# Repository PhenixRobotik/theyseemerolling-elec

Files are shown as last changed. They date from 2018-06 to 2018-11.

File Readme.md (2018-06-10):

# Électronique pour "They see me rolling",  la base roulante de PhenixRobotik.

<div class="alert alert-warning">
    This project requires KiCAD 5.0 and is not compatible with previous versions (software and libraries).
</div>

* Stm32f3 (?)
  * Voltage instrumentation (power, digital)
  * Power current instrumentation

* IOs :
  * Power alimentation
  * Digital alimentation
  * JTAG debug (daisy-chain)
  * CAN Bus (daisy-chain)
  * UART ?

* 2 roues codeuses + 2 encodeurs rotatifs :
  * (suggestion salamandar) [Broadcom AS22-M570-xxxx](https://www.mouser.fr/ProductDetail/Broadcom/AS22-M570-4U14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)
    * Ø22mm × 10.9mm
    * 360 cpr to 2048 cpr
    * dual-channel + index channel
    * 5V

* 2 moteurs Maxon DC + 2 encodeurs rotatifs

* Driver moteurs
  * (suggestion salamandar) [ST L6207](http://www.st.com/content/st_com/en/products/motor-drivers/brushed-dc-motor-drivers/l6207.html)
    * POWERSO36
    * Operating supply voltage from 8 to 52 V
    * 5.6 A output peak current (2.8 A DC)
    * PWM current controllers
    * Operating frequency up to 100 KHz
    
* Current measurement
    * torque estimation / control
    * Way of doing it : Use a driver which provides this feature / shunt resistor / Hall effect sensor ?
    
* Architecture:
    * One single PCB card
    * One motor driver card (speed + torque control) + one position (+ odometrie ?) card ( = carte kiwi ?)
    * Two motor driver cards (speed + torque control) + one position (+ odometrie ?) card ( = carte kiwi ?)

## Eventually :

* IMU / 9-axes
* ...

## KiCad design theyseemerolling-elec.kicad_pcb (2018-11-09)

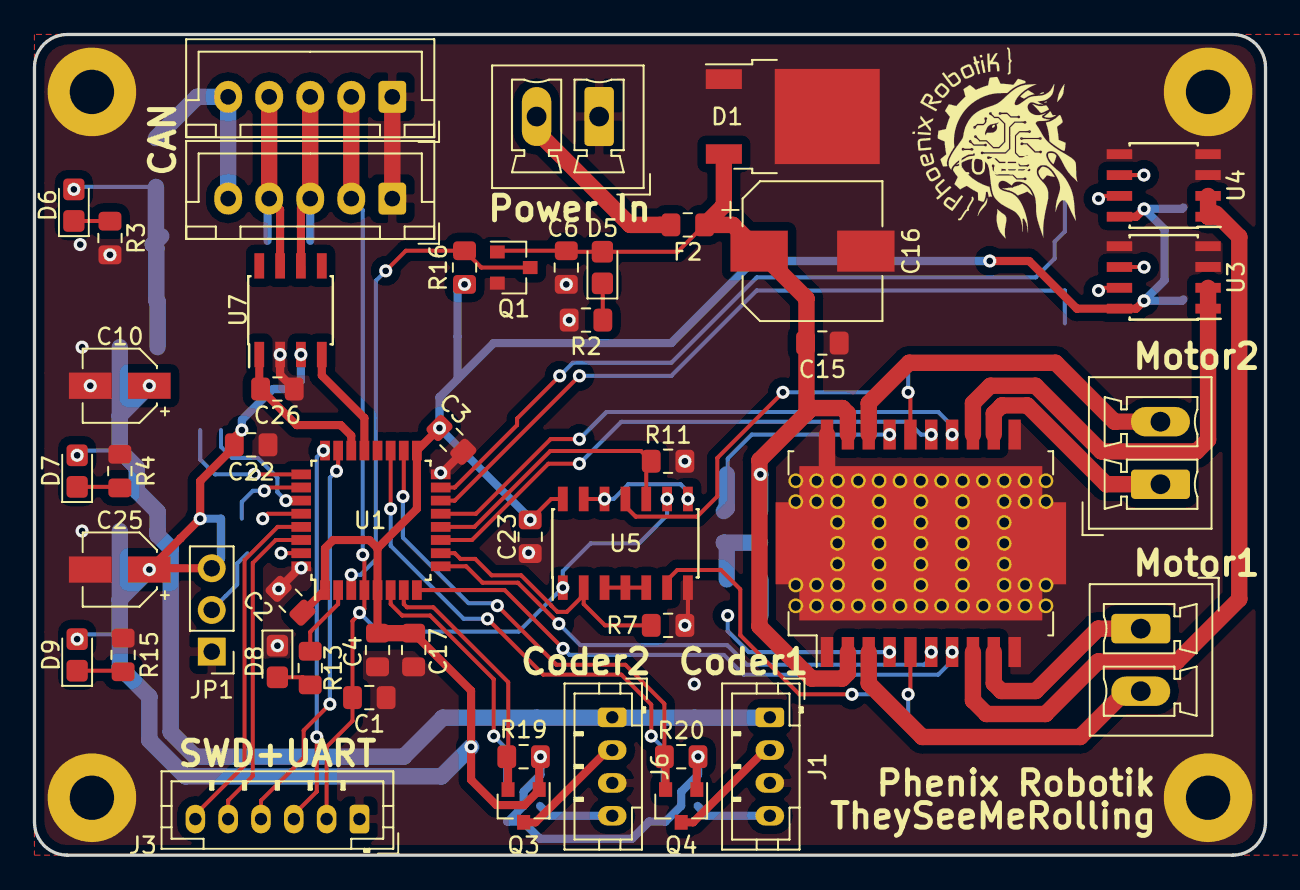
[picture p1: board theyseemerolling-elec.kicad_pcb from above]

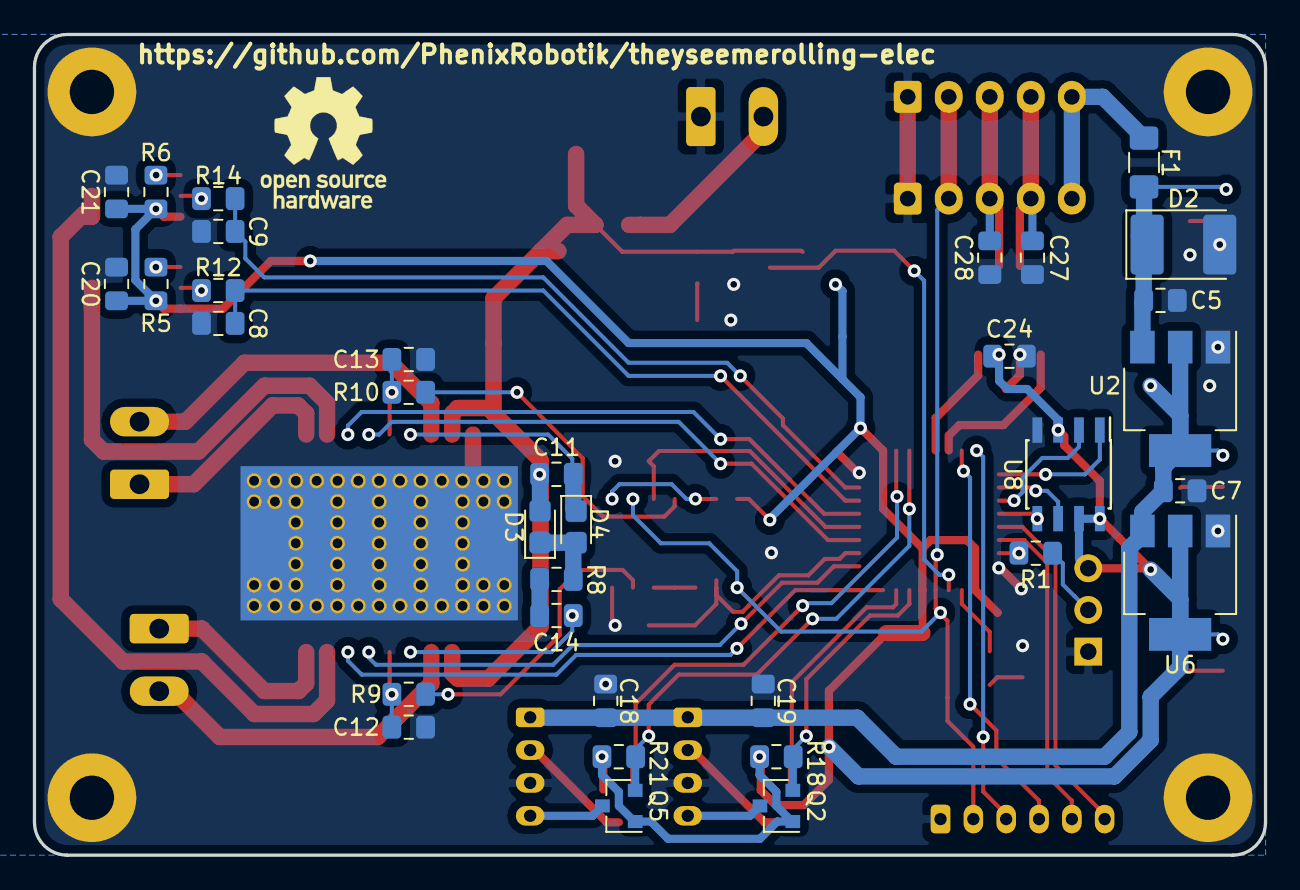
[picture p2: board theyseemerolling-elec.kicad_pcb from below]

Board: 2 copper layers, 75.0 x 50.0 mm, 88 parts (35 on the bottom side), 65 nets.

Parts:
C1, C2, C3, C4, C5, C7, C15: 100n; C_0805_2012Metric_Pad1.15x1.40mm_HandSolder
C6: C; C_0805_2012Metric_Pad1.15x1.40mm_HandSolder
C8, C9: 1n; C_0805_2012Metric_Pad1.15x1.40mm_HandSolder
C10, C25: 10u; CP_Elec_4x5.4
C11: 220n; C_0805_2012Metric_Pad1.15x1.40mm_HandSolder
C12, C13: 5.6n; C_0805_2012Metric_Pad1.15x1.40mm_HandSolder
C14: 10n; C_0805_2012Metric_Pad1.15x1.40mm_HandSolder
C16: 100u; CP_Elec_8x10
C17: 4.7u; C_0805_2012Metric_Pad1.15x1.40mm_HandSolder
C18, C19, C20, C21, C22, C23, C24: 100nF; C_0805_2012Metric_Pad1.15x1.40mm_HandSolder
C26, C27, C28: 100p; C_0805_2012Metric_Pad1.15x1.40mm_HandSolder
D1: D_Schottky_AAK; TO-252-2
D2: D; D_2114_3652Metric_Castellated
D3, D4: 1N4148; D_0805_2012Metric_Castellated
D5, D6, D7, D8, D9: LED_ALT; LED_0805_2012Metric_Castellated
F1: Polyfuse 2A; Fuse_1206_3216Metric_Pad1.42x1.75mm_HandSolder
F2: 5A; Fuse_0805_2012Metric_Pad1.15x1.40mm_HandSolder
IC2: L6205PD; ST_PowerSO-20_SlugDown_ThermalVias
J1: Conn_Encoder1; JST_PH_B4B-PH-K_1x04_P2.00mm_Vertical
J2: Conn_Power_In; PhoenixContact_MCV_1,5_2-G-3.81_1x02_P3.81mm_Vertical
J3: Conn_SWD_UART; JST_PH_B6B-PH-K_1x06_P2.00mm_Vertical
J4: Conn_Mot1; PhoenixContact_MCV_1,5_2-G-3.81_1x02_P3.81mm_Vertical
J5: Conn_Mot2; PhoenixContact_MCV_1,5_2-G-3.81_1x02_P3.81mm_Vertical
J6: Conn_Encoder2; JST_PH_B4B-PH-K_1x04_P2.00mm_Vertical
J7, J8: CAN_conn; JST_XH_B05B-XH-A_1x05_P2.50mm_Vertical
JP1: JP_Select_Boot; PinHeader_1x03_P2.54mm_Vertical
LOGO1: Logo_Open_Hardware_Large; OSHW-Logo_7.5x8mm_SilkScreen
LOGO2: Logo_Open_Hardware_Small; Logo_14,5mm
MK1, MK2, MK3, MK4: MountingHole_Pad; MountingHole_2.7mm_M2.5_Pad
Q1, Q2, Q3, Q4, Q5: BSS138; SOT-23
R1, R5, R6, R7, R11, R16: 10kR; R_0805_2012Metric_Pad1.15x1.40mm_HandSolder
R2, R3, R4, R15: R_LED; R_0805_2012Metric_Pad1.15x1.40mm_HandSolder
R8: 100R; R_0805_2012Metric_Pad1.15x1.40mm_HandSolder
R9, R10: 100k; R_0805_2012Metric_Pad1.15x1.40mm_HandSolder
R12, R14: R_Sense; R_0805_2012Metric_Pad1.15x1.40mm_HandSolder
R13: 1kR; R_0805_2012Metric_Pad1.15x1.40mm_HandSolder
R18, R19, R20, R21: R; R_0805_2012Metric_Pad1.15x1.40mm_HandSolder
U1: STM32F303K8Tx; LQFP-32_7x7mm_P0.8mm
U2: LD1117S50TR_SOT223; SOT-223-3_TabPin2
U3, U4: ACS711xLCTR-12AB; SOIC-8_3.9x4.9mm_P1.27mm
U5: 74HC00; SOIC-14_3.9x8.7mm_P1.27mm
U6: LD1117S33TR_SOT223; SOT-223-3_TabPin2
U7: TCAN332; SOIC-8_3.9x4.9mm_P1.27mm
U8: AT25SF041; SOIC-8_3.9x4.9mm_P1.27mm

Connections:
+3V3: C2.1, C3.1, C4.1, C17.2, C20.2, C21.2, C22.2, C23.1, C24.1, C25.1, D9.2, JP1.3, Q2.1, Q3.1, Q4.1, Q5.1, R5.1, R6.1, R16.1, R18.1, R19.2, R20.1, R21.2, U1.1, U1.5, U1.17, U3.8, U4.8, U5.14, U6.2, U7.3, U8.3, U8.7, U8.8
+5V: C7.1, C10.1, C18.1, C19.1, D7.2, J1.1, J6.1, U2.2, U6.3
/CAN/+7V_CAN: F1.2, J7.5, J8.5
/CAN/NRST: C1.2, J3.2, J7.2, J8.2, U1.4, U5.1, U5.9
/DualDCDriver/EN_A: R9.2, U5.6
/DualDCDriver/EN_B: R10.2, U5.11
/DualDCDriver/IN1_A: IC2.6, U1.9
/DualDCDriver/IN1_B: IC2.14, U1.13
/DualDCDriver/IN2_A: IC2.7, U1.8
/DualDCDriver/IN2_B: IC2.15, U1.11
/DualDCDriver/M1+: IC2.9, J4.1
/DualDCDriver/M1-: IC2.3, J4.2
/DualDCDriver/M2+: IC2.12, J5.1
/DualDCDriver/M2-: IC2.18, J5.2
/DualDCDriver/Sense_A: R14.1, U4.7
/DualDCDriver/Sense_A_Fault: R6.2, U4.6
/DualDCDriver/Sense_B: R12.1, U3.7
/DualDCDriver/Sense_B_Fault: R5.2, U3.6
/f3/ABOUT_DA_POWER: Q1.3, R16.2, U1.3
/f3/CAN_RX: U1.21, U7.4
/f3/CAN_TX: C26.1, U1.22, U7.1
/f3/EN_A_and_NRST: R7.2, U1.10, U5.2
/f3/EN_B_and_NRST: R11.1, U1.12, U5.10
/f3/Encoder_1_A: J1.2, Q4.3
/f3/Encoder_1_B: J1.4, Q5.3
/f3/Encoder_2_A: J6.2, Q3.3
/f3/Encoder_2_B: J6.4, Q2.3
/f3/MISO: U1.27, U8.2
/f3/MOSI: U1.28, U8.5
/f3/RX_1: J3.5, U1.30
/f3/SCK: U1.26, U8.6
/f3/Sense_A_Filtered: C9.1, R14.2, U1.15
/f3/Sense_B_Filtered: C8.1, R12.2, U1.14
/f3/TCK: J3.3, U1.24
/f3/TMS: J3.4, U1.23
/f3/TX_1: J3.6, U1.29
GND: C1.1, C2.2, C3.2, C4.2, C5.2, C6.2, C7.2, C8.2, C9.2, C10.2, C12.2, C13.2, C15.2, C16.2, C17.1, C18.2, C19.2, C20.1, C21.1, C22.1, C23.2, C24.2, C25.2, C26.2, C27.1, C28.2, D1.1, D1.2, D2.2, D8.1, IC2.1, IC2.10, IC2.11, IC2.20, IC2.21, J1.3, J2.1, J3.1, J6.3, J7.1, J8.1, JP1.1, MK1.1, MK2.1, MK3.1, MK4.1, Q1.2, R2.2, R3.2, R4.2, R7.1, R11.2, R15.2, U1.16, U1.32, U2.1, U3.3, U3.4, U3.5, U4.3, U4.4, U4.5, U5.7, U6.1, U7.2, U8.4
unnamed: C5.1, D2.1, D6.2, F1.1, U2.3
unnamed: C11.2, D4.1, IC2.17
unnamed: C12.1, IC2.5, R9.1
unnamed: C13.1, IC2.16, R10.1
unnamed: C14.1, IC2.4
unnamed: C14.2, R8.1
unnamed: C27.2, J7.4, J8.4, U7.7
unnamed: C28.1, J7.3, J8.3, U7.6
unnamed: D3.1, D4.2, R8.2
unnamed: D5.1, R2.1
unnamed: D6.1, R3.1
unnamed: D7.1, R4.1
unnamed: D8.2, R13.1
unnamed: D9.1, R15.1
unnamed: F2.2, J2.2
unnamed: IC2.8, U4.1, U4.2
unnamed: IC2.13, U3.1, U3.2
unnamed: JP1.2, R1.2
unnamed: Q2.2, R18.2, U1.6
unnamed: Q3.2, R19.1, U1.7
unnamed: Q4.2, R20.2, U1.18
unnamed: Q5.2, R21.1, U1.19
unnamed: R1.1, U1.31
unnamed: R13.2, U1.2
unnamed: U1.25, U8.1
unnamed: U5.3, U5.4, U5.5
unnamed: U5.8, U5.12, U5.13
VCC: C6.1, C11.1, C15.1, C16.1, D1.3, D3.2, D5.2, F2.1, IC2.2, IC2.19, Q1.1

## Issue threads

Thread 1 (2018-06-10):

[power_regul] Diode D1 reverse

Salamandar, 2018-06-10:
La diode D1 reverse sert, je suppose, à absorber le courant en cas d'alim inversée.
Si c'est le cas, pourquoi ne pas mettre (aussi ?) une diode en directe entre power_input et power ?

LTrMN, 2018-06-10:
C'est ça, et quand il y a inversion le fusible doit sauter (attention au dimensionnement de la diode par rapport au fusible). Si on ne met pas la diode en inverse, c'est pour éviter de faire passer toute la puissance dans cette diode, et donc de chauffer et perdre de l'énergie inutilement.

Salamandar, 2018-06-10:
> Si on ne met pas la diode en inverse

Tu voulais dire directe ?

En tout cas je comprends, donc je retire ce que j'ai dit.

LTrMN, 2018-06-10:
Oui

Closed 2018-06-10.

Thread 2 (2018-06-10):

[power_regul] Elec_input = 7V, regul 5v

Salamandar, 2018-06-10:
Ce qu'il se passe sur le bus n'est pas contrôlé par la board (interférences, proximité des câbles de puissance, etc), il faudrait donc un régul 5v sur la board.

Cela "oblige" à fournir par le bus plus de 5v (parce que le régul sera certainement un step down). Certaines équipes se fixent sur 7.5v. Sur notre aspirateur robot je crois que c'était 7V. Mais dans le détail, on s'en fout : Il faut un régul 5v (en parallèle ou en amont du régul 3v3 ?).

LTrMN, 2018-06-10:
en amont avec de LOD (faible chute pour le 3.3V), on perd moins de puissance, après oui j'hésitais entre propager un +5V qui sert à tout les processeurs et capteurs, avec éventuellement une autre régul à +3.3V, ou propager une tension supérieure à 5V (au moins 6V), puis une régul à 5V par carte. Après 7,4V c'est parceque c'est une tension de lipo 2s, donc on est pas obligé de ce fixer sur cette tension, il faut tirer le courant sur toutes les cellules en même temps c'est mieux.

Mais pourquoi il faut pas que le +5V soit le même distribué à chaque carte? Avec des capas de découplage ça doit être bon?

Salamandar, 2018-06-10:
> Mais pourquoi il faut pas que le +5V soit le même distribué à chaque carte? Avec des capas de découplage ça doit être bon?

C'est aussi : On va tirer du courant, donc il y aura des chutes de courant, forcément. Donc il *faut* un régul (oui j'ai pas dit ça dans le message original). Et si on veut mettre un régul, il faut comme tu le dis au moins 6V ;)
Et je disais step-down en opposition à step-up, pas en opposition à LDO. En effet pour l'électronique, mieux vaudra un low drop qui a une efficacité meilleure.

LTrMN, 2018-06-10:
Après sur le +5V avec les capteurs et les f3 (Raspberry sur un rail à part quand même), je suis pas convaincu qu'on tire un courrant assez fort pour engendrer une chute significative, mais en même temps c'est pas compliqué de rajouter un régul pour le +5V

Salamandar, 2018-06-10:
> Raspberry sur un rail à part quand même

Ah putain t'as raison, il faudra prévoir ça sur la carte alim (genre une sortie usb "standard").

> je suis pas convaincu qu'on tire un courrant assez fort pour engendrer une chute significative

Oublie pas que c'est ça qui va alimenter la majorité des capteurs (qui peuvent tirer un petit peu par pics) et actionneurs (pour les servos, ça se discute, certes, mais mieux vaut qu'ils ne soient pas influencés par l'alim moteur, et ils sont forcément sur la même masse que le MCU qui les contrôle).

LTrMN, 2018-06-10:
> (pour les servos, ça se discute, certes, mais mieux vaut qu'ils ne soient pas influencés par l'alim moteur, et ils sont forcément sur la même masse que le MCU qui les contrôle).
Tu mets pas des servos sur l'alim +5V des capteurs.

Salamandar, 2018-06-10:
D'où l'idée que ça se discute. Mon avis est :
* On va pas les alimenter par l'alim moteurs
* On va pas multiplier les alims en mode yolo
Après t'as raison que utiliser l'alim des capteurs n'est pas très propre.

LTrMN, 2018-06-10:
Donc du coup:

- Une alim 7-8V pour les capteurs et f3

- Une alim +5V bourir pour la raspberry

- l'alim séparée des moteurs

Closed 2019-09-08.

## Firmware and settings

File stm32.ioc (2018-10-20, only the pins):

Mcu.UserName=STM32F303K8Tx
PA0.GPIO_Label=Encoder_2_B [TIM2_CH1]
PA0.Signal=S_TIM2_CH1_ETR
PA1.GPIO_Label=Encoder_2_A [TIM2_CH2]
PA1.Signal=S_TIM2_CH2
PA10.GPIO_Label=Sense_B_Fault
PA10.Signal=GPIO_Input
PA11.Signal=CAN_RX
PA12.Signal=CAN_TX
PA13.Signal=SYS_JTMS-SWDIO
PA14.Signal=SYS_JTCK-SWCLK
PA15.GPIO_Label=SPI1_CS
PA15.Signal=GPIO_Output
PA2.GPIO_Label=IN2_A
PA2.Signal=GPIO_Output
PA3.GPIO_Label=IN1_A
PA3.Signal=GPIO_Output
PA4.GPIO_Label=EN_A [TIM3_CH2]
PA4.Signal=S_TIM3_CH2
PA5.GPIO_Label=IN2_B
PA5.Signal=GPIO_Output
PA6.GPIO_Label=EN_B [TIM3_CH1]
PA6.Signal=S_TIM3_CH1
PA7.GPIO_Label=IN1_B
PA7.Signal=GPIO_Output
PA8.GPIO_Label=Encoder_1_A [TIM1_CH1]
PA8.Signal=S_TIM1_CH1
PA9.GPIO_Label=Encoder_1_B [TIM1_CH2]
PA9.Signal=S_TIM1_CH2
PB0.GPIO_Label=Sense_B_Filtered [ADC1_IN11]
PB0.Signal=ADC1_IN11
PB1.GPIO_Label=Sense_A_Filtered [ADC1_IN12]
PB1.Signal=ADC1_IN12
PB3.Signal=SPI1_SCK
PB4.Signal=SPI1_MISO
PB5.Signal=SPI1_MOSI
PB6.Signal=USART1_TX
PB7.Signal=USART1_RX

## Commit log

2018-05-22 Add KiCAD gitignore, Readme.md
2018-05-22 add st/tsop libs, basic kicad files.
    [theyseemerolling-elec.kicad_pcb, theyseemerolling-elec.sch]
2018-05-23 fix project
    [theyseemerolling-elec.sch]
2018-05-23 Add DualDCDriver sub-schematics, with two designs.
    [DualDCDriver.sch, theyseemerolling-elec.kicad_pcb, theyseemerolling-elec.sch]
2018-05-24 Add kicad version warning
2018-05-24 default-ly place component on pcb
    [theyseemerolling-elec.kicad_pcb]
2018-05-24 Add connectors for dummy pcb routing
    [theyseemerolling-elec.sch]
2018-05-24 route L6205
    [theyseemerolling-elec.kicad_pcb]
2018-06-09 Remove duplicates, remove motors and add connectors
    [DualDCDriver.sch, theyseemerolling-elec.sch]
2018-06-09 PCB: remove duplicate, add 10cm×5cm board outline
    [theyseemerolling-elec.kicad_pcb]
2018-06-10 f3 and current sensors added
    [DualDCDriver.sch, f3.sch, power_regul.sch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]
2018-06-11 logic to stop motors in reset state and current sense filter
    [DualDCDriver.sch, f3.sch, power_regul.sch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]
2018-06-11 input 7V 5V regulator
    [f3.sch, power_regul.sch, theyseemerolling-elec.sch]
2018-06-12 CAN tranciever added and f3 wired
    [CAN.sch, DualDCDriver.sch, f3.sch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]
2018-06-17 JTAG pins and power presence
    [f3.sch, power_regul.sch, theyseemerolling-elec.sch]
2018-06-17 forgot to connecte the led
    [f3.sch, theyseemerolling-elec.sch]
2018-06-17 Fix can_conn usage
    [CAN.sch]
2018-09-28 change some symbol names for conformity
    [CAN.sch, f3.sch, power_regul.sch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]
2018-09-28 update schemas, cleanup, renames
    [CAN.sch, DualDCDriver.sch, f3.sch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]
2018-09-28 Updated PCB. logic is almost done, power is left to do
    [CAN.sch, theyseemerolling-elec.kicad_pcb, theyseemerolling-elec.sch]
2018-09-29 change connectors. Add swd.
    [power_regul.sch, theyseemerolling-elec.sch]
2018-09-29 Change GNDD -> GND
    [DualDCDriver.sch]
2018-09-29 routing finished
    [theyseemerolling-elec.kicad_pcb]
2018-09-30 SPI flash added, JTAG removed, uart connector added
    [CAN.sch, DualDCDriver.sch, f3.sch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]
2018-09-30 move text
    [theyseemerolling-elec.kicad_pcb]
2018-10-01 clean libraries
    [CAN.sch, DualDCDriver.sch, f3.sch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]
2018-10-01 Remap STM32 with stm32cubemx
    [f3.sch, theyseemerolling-elec.kicad_pcb, theyseemerolling-elec.sch]
2018-10-01 Use molex connectors
    [CAN.sch, DualDCDriver.sch, f3.sch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]
2018-10-02 Set footprints, values for capas
    [CAN.sch, DualDCDriver.sch, f3.sch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]
2018-10-02 add mounting holes
    [theyseemerolling-elec.sch]
2018-10-03 Use correct footprints, merge uart + swd connectors
    [DualDCDriver.sch, theyseemerolling-elec.sch]
2018-10-03 PCB refactored, down to 80mm, correct footprints.
    [theyseemerolling-elec.kicad_pcb]
2018-10-03 Finished board, kinda cleaned up
    [f3.sch, theyseemerolling-elec.kicad_pcb]
2018-10-03 decouplage des alims
    [CAN.sch, DualDCDriver.sch, f3.sch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]
2018-10-03 Fix CAN_conn
    [theyseemerolling-elec.kicad_pcb]
2018-10-03 cleanup pcb, reorganize text
    [theyseemerolling-elec.kicad_pcb]
2018-10-03 Add text and logos
    [theyseemerolling-elec.kicad_pcb, theyseemerolling-elec.sch]
2018-10-07 rename components
    [CAN.sch, DualDCDriver.sch, f3.sch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]
2018-10-07 Change connectors for JST
    [CAN.sch, DualDCDriver.sch, f3.sch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]
2018-10-07 Use JST_PH connectors for encoders. Re-route with new connectors.
    [theyseemerolling-elec.kicad_pcb, theyseemerolling-elec.sch]
2018-10-08 Add script to autogenerate gerber zip. update submodule.
2018-10-08 autodetect kicad_pcb file
2018-10-10 level conversion, to check and route
    [CAN.sch, DualDCDriver.sch, f3.sch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]
2018-10-10 correction, to route
    [CAN.sch, theyseemerolling-elec.kicad_pcb]
2018-10-13 Added BSS138 on MCP2551, need to route
    [CAN.sch, power_regul.sch]
2018-10-13 Fixed mounting holes schematic
    [theyseemerolling-elec.sch]
2018-10-13 footprint 0805
    [CAN.sch, theyseemerolling-elec.kicad_pcb]
2018-10-20 Schematic modifications, to be checked
    [CAN.sch, DualDCDriver.sch, f3.sch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]
2018-10-20 fix libraries
    [CAN.sch, DualDCDriver.sch, f3.sch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]
2018-10-21 Change CAN driver for 3v3 compliancy.
    [CAN.sch, DualDCDriver.sch, f3.sch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]
2018-10-21 Start to put components on both sides
    [theyseemerolling-elec.kicad_pcb]
2018-10-28 update schema, pcb, use double face components, tht jumper.
    [CAN.sch, DualDCDriver.sch, f3.sch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]
2018-11-01 Rename schema library
    [DualDCDriver.sch]
2018-11-01 Use new footprint
    [theyseemerolling-elec.kicad_pcb]
2018-11-01 Update from pcb after symbol changes
    [theyseemerolling-elec.kicad_pcb]
2018-11-01 update gitignore and phenix_kicad
    [theyseemerolling-elec.kicad_pcb]
2018-11-01 update pcb a bit
    [theyseemerolling-elec.kicad_pcb]
2018-11-02 remove wire
    [theyseemerolling-elec.kicad_pcb]
2018-11-02 Fusionner les segments superposés
    [theyseemerolling-elec.kicad_pcb]
2018-11-04 change components
    [CAN.sch, theyseemerolling-elec.sch]
2018-11-04 Références
    [theyseemerolling-elec.kicad_pcb]
2018-11-04 Add text
    [theyseemerolling-elec.kicad_pcb]
2018-11-04 Change connectors. reduce size.
    [CAN.sch, DualDCDriver.sch, f3.sch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]
2018-11-05 fix phoenix/phenix
    [theyseemerolling-elec.kicad_pcb, theyseemerolling-elec.sch]
2018-11-05 Fix : use new footprints
    [CAN.sch, DualDCDriver.sch, f3.sch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]
2018-11-05 Cleanup, check footprints, connect mounting holes to GND
    [theyseemerolling-elec.kicad_pcb, theyseemerolling-elec.sch]
2018-11-05 Move silkscreen
    [theyseemerolling-elec.kicad_pcb]
2018-11-07 Changed fuse footprint
    [CAN.sch, DualDCDriver.sch, f3.sch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]
2018-11-09 Fix footprint on pcb
    [theyseemerolling-elec.kicad_pcb]
2019-03-31 Add maxon PCB for motor
    [maxon_pcb.kicad_pcb, maxon_pcb.sch]
